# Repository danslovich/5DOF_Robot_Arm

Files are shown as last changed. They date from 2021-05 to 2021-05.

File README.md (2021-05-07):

# 5DOF_Robot_Arm
All Files to create your own 5DOF robot arm using the Dynamixel XL-330.
The Dynamixel XL-330-M288-T micro servos and the Arduino MKR shield were provided by ROBOTIS. 

https://www.robotis.us/

https://www.robotis.us/dynamixel-xl330-m288-t/

https://www.robotis.us/robotis-blog/dynamixel-xl330-mkr-shield/

All parts were 3D printed using an Ender 3 V2 and all associated hardware was purchased on 
amazon. You will need 1/2" m4 machine screws, washers, and bearings. Links below will take 
you to amazon listings for acceptable hardware.

https://www.amazon.com/gp/product/B00F34Z5VC/ref=ppx_yo_dt_b_asin_title_o02_s00?ie=UTF8&psc=1

https://www.amazon.com/gp/product/B082PYSPR6/ref=ppx_yo_dt_b_asin_title_o02_s00?ie=UTF8&psc=1

https://www.amazon.com/gp/product/B07DNZMNT1/ref=ppx_yo_dt_b_asin_title_o03_s00?ie=UTF8&psc=1

https://www.amazon.com/gp/product/B07RFFMWZT/ref=ppx_yo_dt_b_asin_title_o02_s02?ie=UTF8&psc=1

All code was written using the Arduino IDE and the arm was controlled with the Arduino and 
the Arduino MKR shield provided by ROBOTIS.

# Fusion 360
Fusion project files and STLs are provided so that you may use, modify, or make your own 5DOF robot arm. Review the project files before printing to ensure accuracy and that you are able to print them on your printer. Models were printed at a 0.12 layer height.

# Arduino
The Arduino MKR Wifi 1010 and the Arduino MKR Dynamixel shield were used for this project. All of the Arduino Code is provided to setup, test and use your daisy chained Dynamixel Xl-330's. You will need to connect servos individually, and run the "scan_dynamixel" to acquire their default ID's then reset them using "ID" to a value that you may then use within your application to implement IK or FK. the "5DOF_Arm_Test"" file uses ID's 1-5 and performs simple motions to confirm the servo movements are accurate.

Have fun!

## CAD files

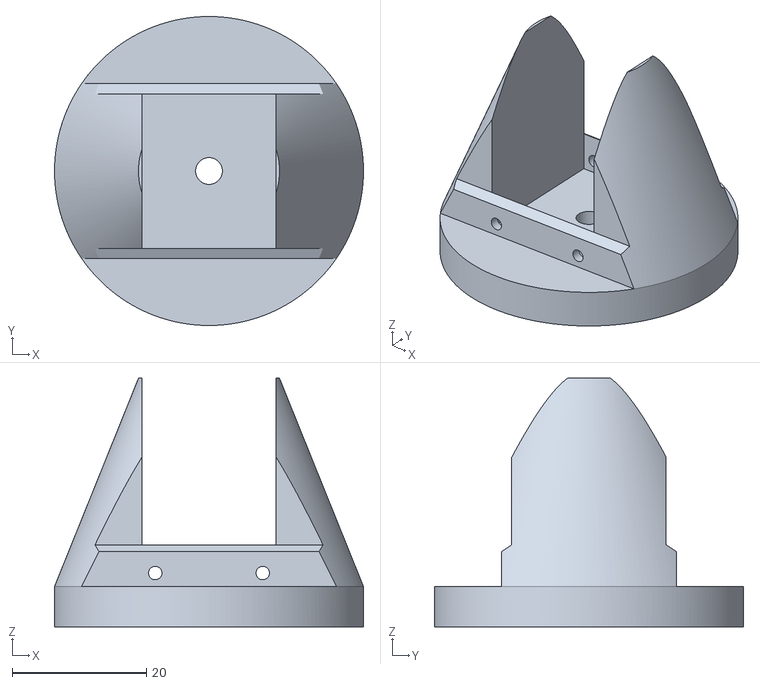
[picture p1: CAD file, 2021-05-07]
Fusion/STLs/hand.stl
46.0 x 46.0 x 37.0

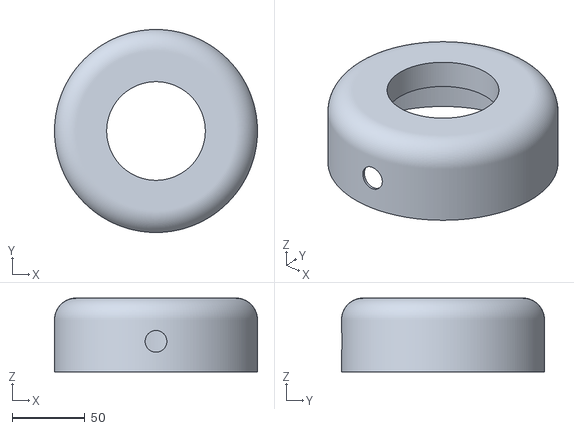
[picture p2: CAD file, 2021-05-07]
Fusion/STLs/base.stl
140.0 x 140.0 x 51.0

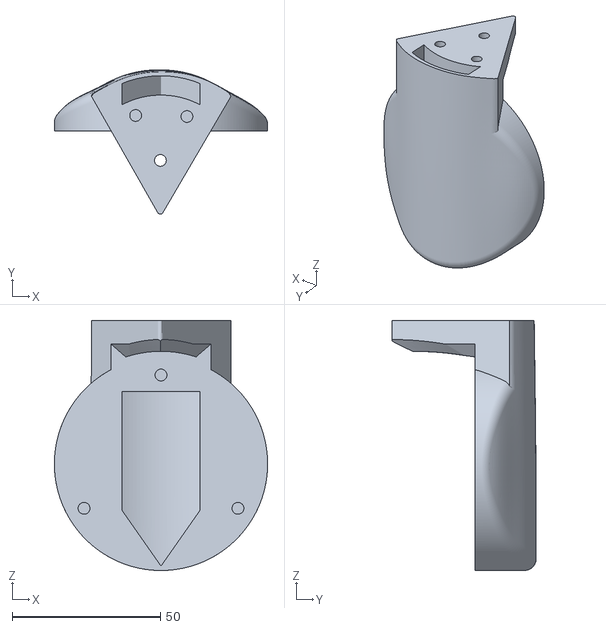
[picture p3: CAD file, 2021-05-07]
Fusion/STLs/shoulder_2.stl
72.0 x 48.7 x 84.4

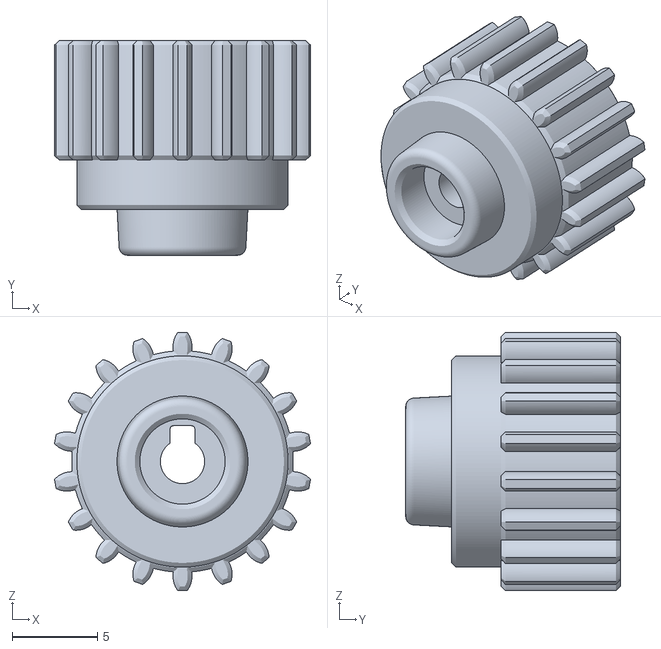
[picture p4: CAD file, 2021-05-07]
Fusion/STLs/Sun_gear.stl
15.0 x 12.6 x 15.2

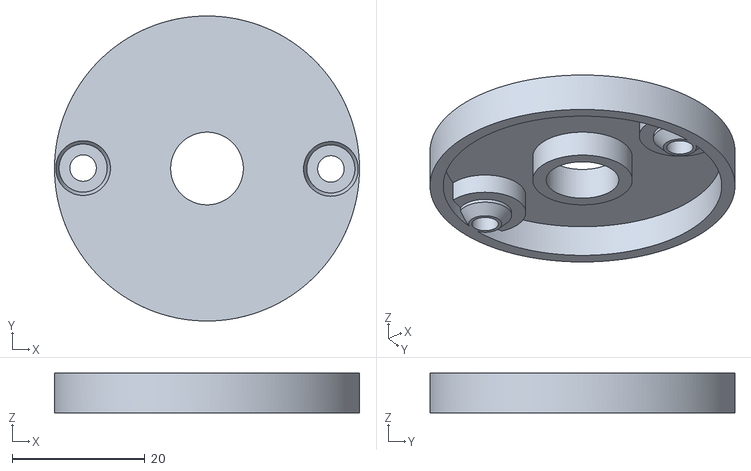
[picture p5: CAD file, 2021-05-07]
Fusion/STLs/hand_plate.stl
46.0 x 46.0 x 6.00

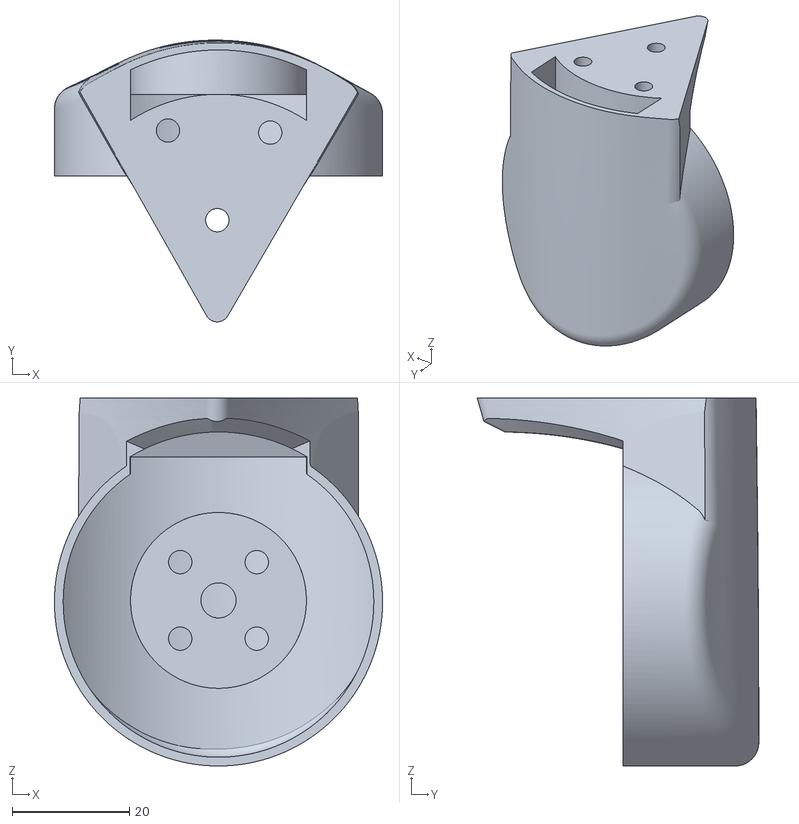
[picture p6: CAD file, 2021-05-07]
Fusion/STLs/elbow_2.stl
56.0 x 48.1 x 62.8

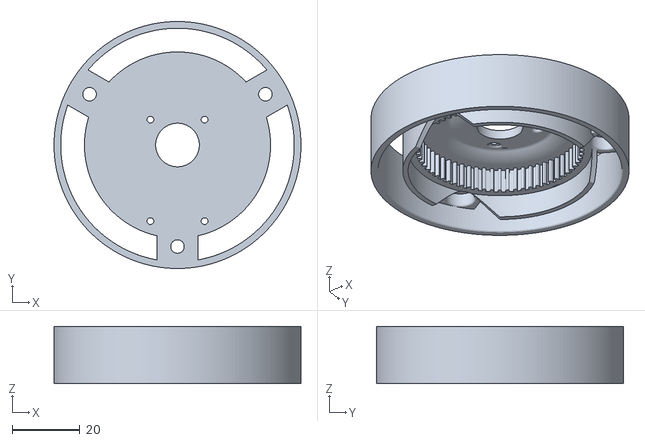
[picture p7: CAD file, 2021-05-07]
Fusion/STLs/planetary_gear_box.stl
73.0 x 73.0 x 16.9

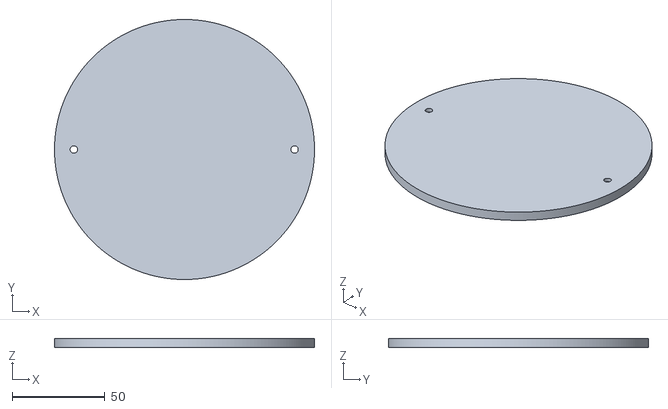
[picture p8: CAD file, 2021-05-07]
Fusion/STLs/base_plate.stl
140.0 x 140.0 x 5.00

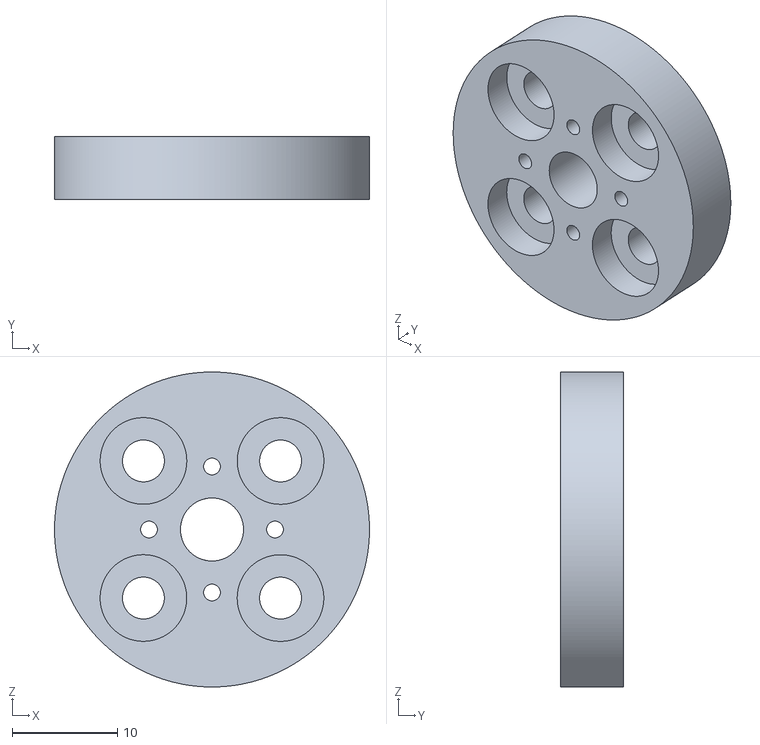
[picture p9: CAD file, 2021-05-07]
Fusion/STLs/elbow_coupler.stl
30.0 x 6.00 x 30.0

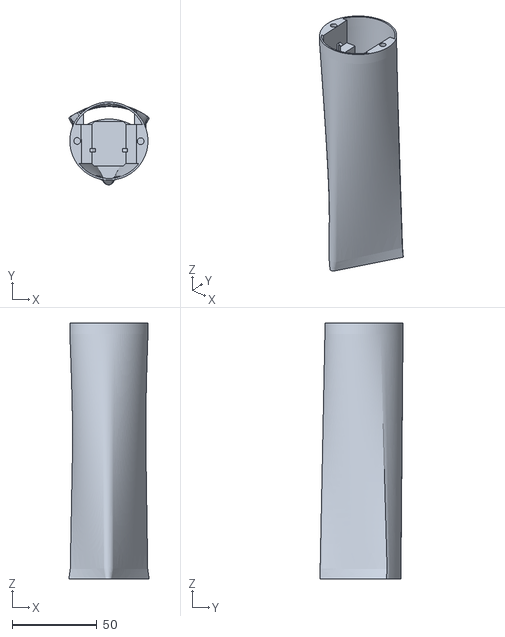
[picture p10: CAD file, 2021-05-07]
Fusion/STLs/link_2.stl
47.3 x 48.8 x 150.7

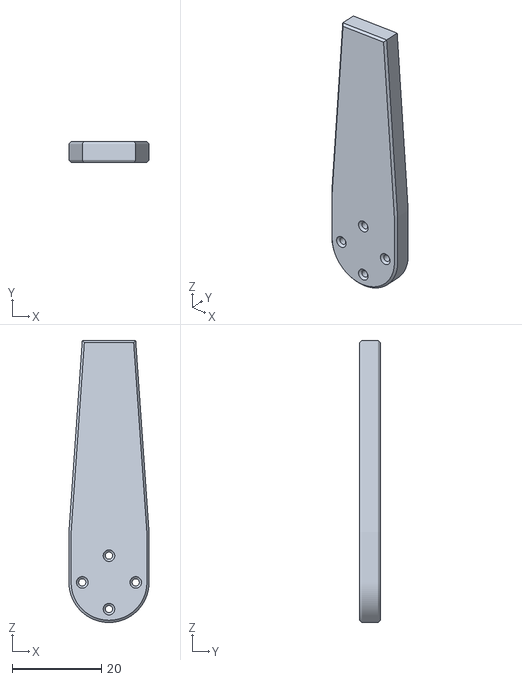
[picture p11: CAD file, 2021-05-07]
Fusion/STLs/eef.stl
18.0 x 4.70 x 63.3

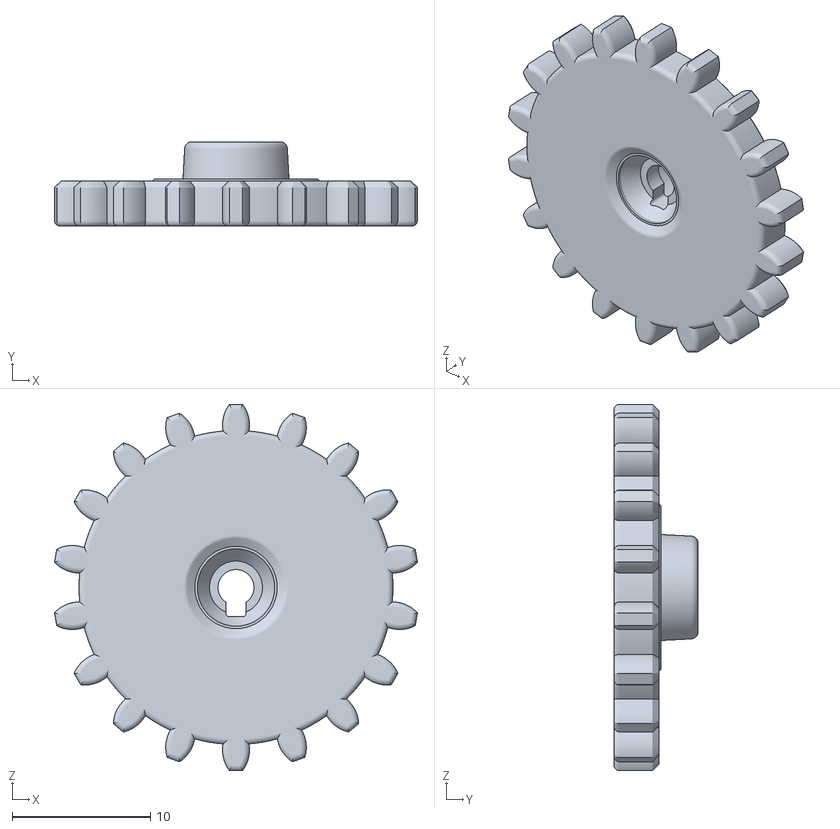
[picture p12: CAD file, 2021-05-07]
Fusion/STLs/wrist_gear_1.stl
26.3 x 6.10 x 26.5

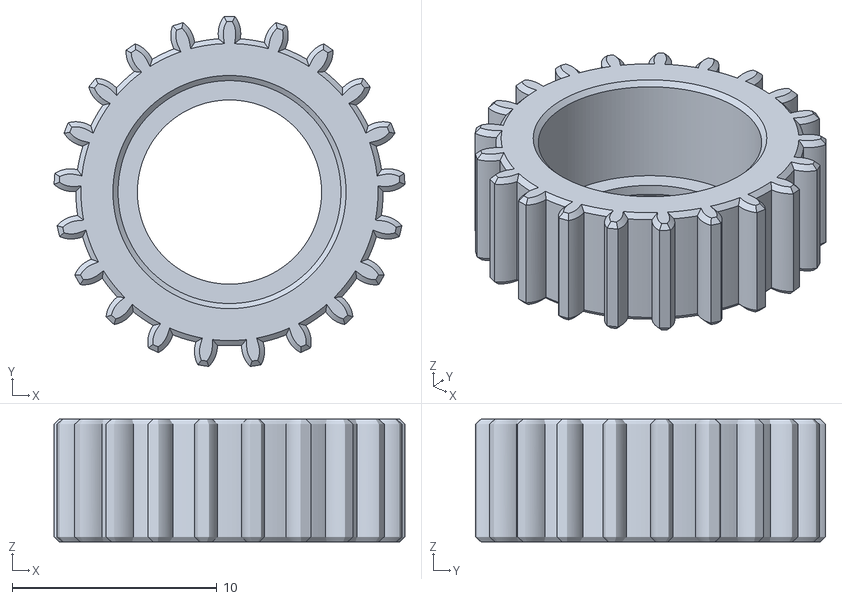
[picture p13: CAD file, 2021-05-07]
Fusion/STLs/planet_gears.stl
17.2 x 17.1 x 6.00

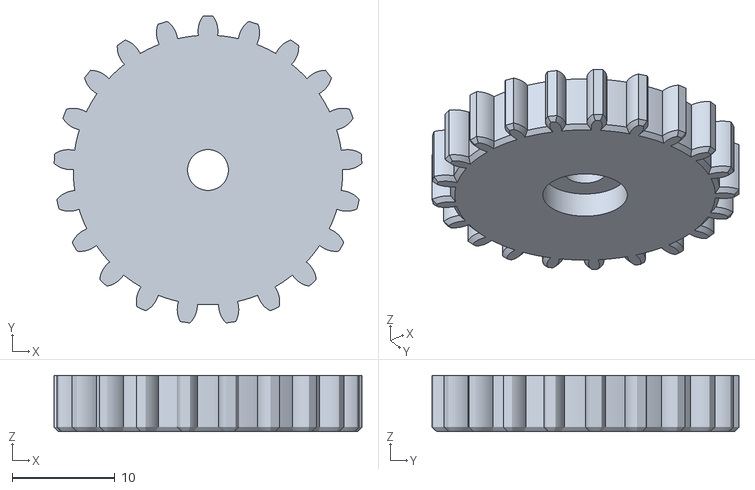
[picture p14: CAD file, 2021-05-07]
Fusion/STLs/wrist_gear_2.stl
30.0 x 29.9 x 5.50

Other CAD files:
Fusion/STLs/shoulder_1.stl
Fusion/STLs/drive_plate.stl
Fusion/STLs/elbow_1.stl
Fusion/Project_Files/5_DOF_ARM.f3d
Fusion/Project_Files/XL-330.f3d

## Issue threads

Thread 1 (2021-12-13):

Connecting base to lower planetary gear box

mdroberts1243, 2021-12-13:
Hi,  Thank-you very much for this design.  Things are going well with quite a bit of components successfully printed so far.

I cannot figure out how the "Shoulder Joint:1" assembly is supposed to connect to the Base.  The dimensions of the STL file that I printed seem a bit off for the Planetary Gear Box to insert into the Base top hole and I'm not sure how to fix it in place if it did fit.

-mark

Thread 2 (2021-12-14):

Are the sun, planet and gearbox STLs up to date?

mdroberts1243, 2021-12-14:
The printed gears from the planetary gearbox seem to look quite different (tooth spacing) from the ones in the Fusion project.  Are the STLs up-to-date?  I seem to be having clearance problems with the STL gears however the mounting holes for the XL-330 in the gearbox are bang on.

mdroberts1243, 2021-12-14:
Using the built-in viewer on Github the STLs look the same as Fusion view... must be a problem with my printer clearances, closing...

Closed 2021-12-14.

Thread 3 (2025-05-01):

License Clarification Request

mbz4, 2025-05-01:
Hello,

Thank you for sharing this great project — I discovered it through [your YouTube video](https://www.youtube.com/watch?v=NCQFlha8_fA).

I noticed the repository doesn’t include a license file.

Would you mind clarifying the permitted uses, or considering attaching a license?

I’m interested in replicating but would like to ensure it’s appropriate first.

Thanks again!

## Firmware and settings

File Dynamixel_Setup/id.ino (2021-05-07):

/*******************************************************************************
*
**
**  Provided by DynamixelShield library examples
**  Modified slightly to assign specific servo id's
**
**
*******************************************************************************/

#include <DynamixelShield.h>

#if defined(ARDUINO_AVR_UNO) || defined(ARDUINO_AVR_MEGA2560)
  #include <SoftwareSerial.h>
  SoftwareSerial soft_serial(7, 8); // DYNAMIXELShield UART RX/TX
  #define DEBUG_SERIAL soft_serial
#elif defined(ARDUINO_SAM_DUE) || defined(ARDUINO_SAM_ZERO)
  #define DEBUG_SERIAL SerialUSB    
#else
  #define DEBUG_SERIAL Serial
#endif


const uint8_t DEFAULT_DXL_ID = 1;
const float DXL_PROTOCOL_VERSION = 2.0;

DynamixelShield dxl;

//This namespace is required to use Control table item names
using namespace ControlTableItem;

void setup() {
  /***
  **
  ** Change Present ID to the id acquired when running "scan_dynamixel"
  ** 
  **/
  uint8_t present_id = /**/100/**/;
  uint8_t new_id = 0;
  
  // For Uno, Nano, Mini, and Mega, use UART port of DYNAMIXEL Shield to debug.
  DEBUG_SERIAL.begin(57600);
  while(!DEBUG_SERIAL);
  
  // Set Port baudrate to 57600bps. This has to match with DYNAMIXEL baudrate.
  dxl.begin(57600);
  // Set Port Protocol Version. This has to match with DYNAMIXEL protocol version.
  dxl.setPortProtocolVersion(DXL_PROTOCOL_VERSION);

  DEBUG_SERIAL.print("PROTOCOL ");
  DEBUG_SERIAL.print(DXL_PROTOCOL_VERSION, 1);
  DEBUG_SERIAL.print(", ID ");
  DEBUG_SERIAL.print(present_id);
  DEBUG_SERIAL.print(": ");
  if(dxl.ping(present_id) == true) {
    DEBUG_SERIAL.print("ping succeeded!");
    DEBUG_SERIAL.print(", Model Number: ");
    DEBUG_SERIAL.println(dxl.getModelNumber(present_id));
    
    // Turn off torque when configuring items in EEPROM area
    dxl.torqueOff(present_id);
    
    // set a new ID for DYNAMIXEL. Do not use ID 200
    new_id = 5;
    if(dxl.setID(present_id, new_id) == true){
      present_id = new_id;
      DEBUG_SERIAL.print("ID has been successfully changed to ");
      DEBUG_SERIAL.println(new_id);

    // set new ID again to ensure completion
      new_id = 5;
      if(dxl.setID(present_id, new_id) == true){
        present_id = new_id;
        DEBUG_SERIAL.print("ID has been successfully established as ");
        DEBUG_SERIAL.println(new_id);
      }else{
        DEBUG_SERIAL.print("Failed to change ID to ");
        DEBUG_SERIAL.println(new_id);
      }
    }else{
      DEBUG_SERIAL.print("Failed to change ID to ");
      DEBUG_SERIAL.println(new_id);
    }
  }
  else{
    DEBUG_SERIAL.println("ping failed!");
  }
}

void loop() {

}

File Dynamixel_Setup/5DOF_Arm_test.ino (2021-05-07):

/*******************************************************************************
*
**  Name: Daniel Slovich
**  Date: 5/7/21
**  Info: Application to setup and test 5DOF robot arm
**        with daisy chained Dynamixel XL-330 micro servos.
**        
**  Note: To assign individual servo id's, connect servos       
**        one at a time and run "scan_dynamixel.ino"
**        and gather default id from serial monitor. 
**        Then run "id.ino" and assigned the desired ID. 
**        Do this for each motor separately before assembly.
*        
*******************************************************************************/

/* NOTE: Please check if your DYNAMIXEL supports Profile Control
* Supported Products : MX-28(2.0), MX-64(2.0), MX-106(2.0), All X series(except XL-320)
* PRO(A) series / PRO+ series
* Designed and tested using the XL-330
*/

#include <DynamixelShield.h>

#if defined(ARDUINO_AVR_UNO) || defined(ARDUINO_AVR_MEGA2560)
  #include <SoftwareSerial.h>
  SoftwareSerial soft_serial(7, 8); // DYNAMIXELShield UART RX/TX
  #define DEBUG_SERIAL soft_serial
#elif defined(ARDUINO_SAM_DUE) || defined(ARDUINO_SAM_ZERO)
  #define DEBUG_SERIAL SerialUSB    
#else
  #define DEBUG_SERIAL Serial
#endif

//DXL ID's set prior using "scan_dynamixel" and "id"
const uint8_t DXL_1 = 1;
const uint8_t DXL_2 = 2;
const uint8_t DXL_3 = 3;
const uint8_t DXL_4 = 4;
const uint8_t DXL_5 = 5;
const float DXL_PROTOCOL_VERSION = 2.0;

DynamixelShield dxl;

//This namespace is required to use Control table item names
using namespace ControlTableItem;

void setup() {
  DEBUG_SERIAL.begin(115200);
  // Set baud rate for DXLs
  dxl.begin(57600);
  dxl.setPortProtocolVersion(DXL_PROTOCOL_VERSION);
  // Check if active
  dxl.ping(DXL_1);
  dxl.ping(DXL_2);
  dxl.ping(DXL_3);
  dxl.ping(DXL_4);
  dxl.ping(DXL_5);

  // Turn off torque when configuring items in EEPROM area
  dxl.torqueOff(DXL_1);
  dxl.torqueOff(DXL_2);
  dxl.torqueOff(DXL_3);
  dxl.torqueOff(DXL_4);
  dxl.torqueOff(DXL_5);
  dxl.setOperatingMode(DXL_1, OP_POSITION);
  dxl.setOperatingMode(DXL_2, OP_POSITION);
  dxl.setOperatingMode(DXL_3, OP_POSITION);
  dxl.setOperatingMode(DXL_4, OP_POSITION);
  dxl.setOperatingMode(DXL_5, OP_POSITION);
  dxl.torqueOn(DXL_1);
  dxl.torqueOn(DXL_2);
  dxl.torqueOn(DXL_3);
  dxl.torqueOn(DXL_4);
  dxl.torqueOn(DXL_5);

  // Set DXLs acceleration and velocity
  dxl.writeControlTableItem(PROFILE_ACCELERATION, DXL_1, 50);//shoulder 4:1 planetary ratio
  dxl.writeControlTableItem(PROFILE_VELOCITY, DXL_1,130);
  dxl.writeControlTableItem(PROFILE_ACCELERATION, DXL_2, 50);//shoulder 4:1 planetary ratio
  dxl.writeControlTableItem(PROFILE_VELOCITY, DXL_2,130);
  dxl.writeControlTableItem(PROFILE_ACCELERATION, DXL_3, 50);//elbow 1:1
  dxl.writeControlTableItem(PROFILE_VELOCITY, DXL_3, 50);
  dxl.writeControlTableItem(PROFILE_ACCELERATION, DXL_4, 50);//wrist 1:1
  dxl.writeControlTableItem(PROFILE_VELOCITY, DXL_4, 130);
  dxl.writeControlTableItem(PROFILE_ACCELERATION, DXL_5, 200);//eef 1:1
  dxl.writeControlTableItem(PROFILE_VELOCITY, DXL_5, 200);

  // Set Home position in angle(degree)
  // These positions correspond to all joints aligned vertically
  // run program to set servo home angles before connecting hardware links/joints
  // Take consideration when assembling to preserve these positions!
  dxl.setGoalPosition(DXL_5, 180.0, UNIT_DEGREE); //shoulder - rotational
  dxl.setGoalPosition(DXL_4, 180.0, UNIT_DEGREE); //shoulder - angular
  dxl.setGoalPosition(DXL_3, 270.0, UNIT_DEGREE); //elbow    - angular
  dxl.setGoalPosition(DXL_2, 180.0, UNIT_DEGREE); //wrist    - rotational
  dxl.setGoalPosition(DXL_1, 180.0, UNIT_DEGREE); //EEF      - angular
  delay(2500);
}

void loop() {
  // Wave hello
  dxl.setGoalPosition(DXL_2, 360.0, UNIT_DEGREE);
  dxl.setGoalPosition(DXL_3, 200.0, UNIT_DEGREE);
  dxl.setGoalPosition(DXL_5, 80.0, UNIT_DEGREE);
  delay(1500);
  dxl.setGoalPosition(DXL_5, 280.0, UNIT_DEGREE);
  delay(500);
  dxl.setGoalPosition(DXL_5, 80.0, UNIT_DEGREE);
  delay(500);
  dxl.setGoalPosition(DXL_5, 280.0, UNIT_DEGREE);
  delay(500);
  dxl.setGoalPosition(DXL_5, 80.0, UNIT_DEGREE);
  delay(500);
  dxl.setGoalPosition(DXL_2, 0.0, UNIT_DEGREE);
  dxl.setGoalPosition(DXL_3, 340.0, UNIT_DEGREE);
  dxl.setGoalPosition(DXL_5, 280.0, UNIT_DEGREE);
  delay(1500);
  dxl.setGoalPosition(DXL_5, 280.0, UNIT_DEGREE);
  delay(500);
  dxl.setGoalPosition(DXL_5, 80.0, UNIT_DEGREE);
  delay(500);
  dxl.setGoalPosition(DXL_5, 280.0, UNIT_DEGREE);
  delay(500);
  dxl.setGoalPosition(DXL_5, 80.0, UNIT_DEGREE);
  delay(500);

  // Return to home
  dxl.setGoalPosition(DXL_5, 180.0, UNIT_DEGREE);
  dxl.setGoalPosition(DXL_4, 180.0, UNIT_DEGREE);
  dxl.setGoalPosition(DXL_3, 270.0, UNIT_DEGREE);
  dxl.setGoalPosition(DXL_2, 180.0, UNIT_DEGREE);
  dxl.setGoalPosition(DXL_1, 180.0, UNIT_DEGREE);
  delay(1500);
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
